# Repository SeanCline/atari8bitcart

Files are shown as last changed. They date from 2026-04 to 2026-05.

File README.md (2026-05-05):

# Cartridge for 8-Bit Atari Computers (400/800/XL/XE)



Configurable Atari 8-bit cartridge PCB for the Atari 400/800/XL/XE line of home computers.

1. **Single 8 KB mode** using one 2764-compatible PROM in the right-hand socket.
2. **Dual 8 KB + 8 KB mode** using two 2764-compatible PROMs.
3. **Single 16 KB mode** using one 27128-compatible PROM in the right-hand socket along with a `74AHCT1G08` for chip-enable logic.

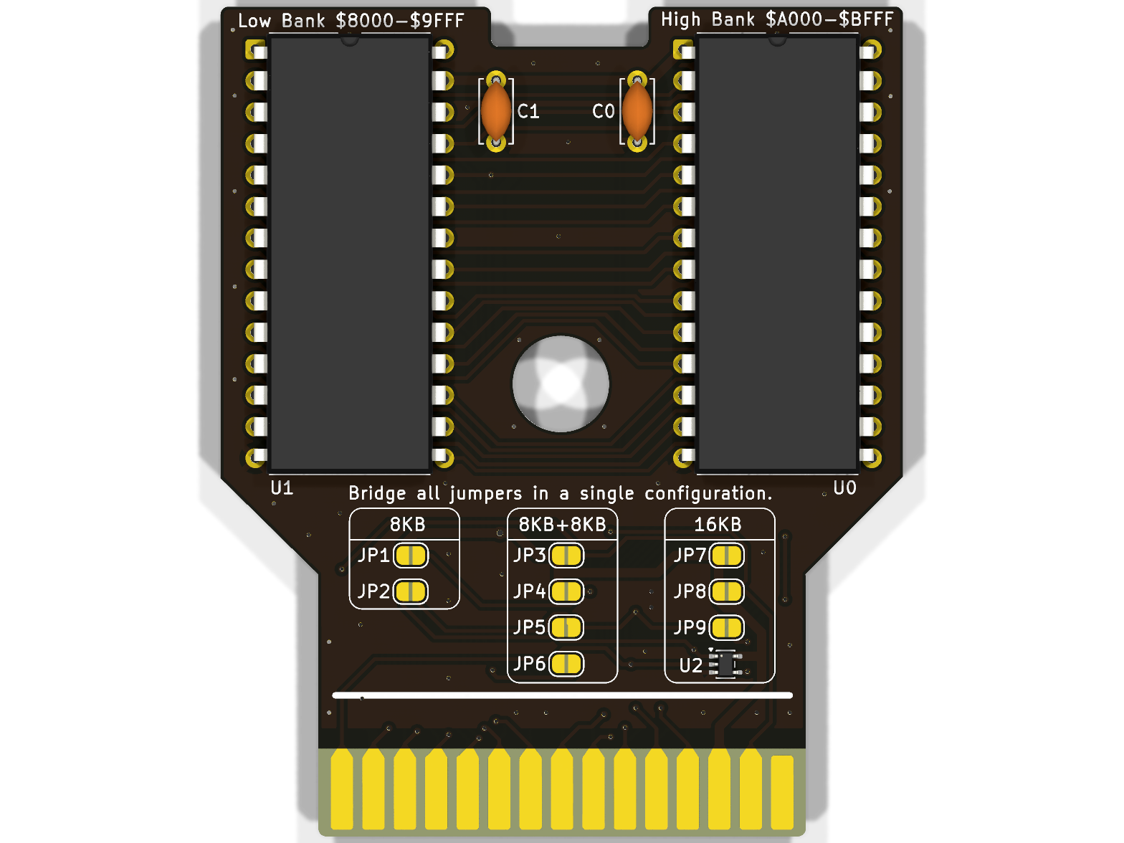
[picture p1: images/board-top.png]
Board top view

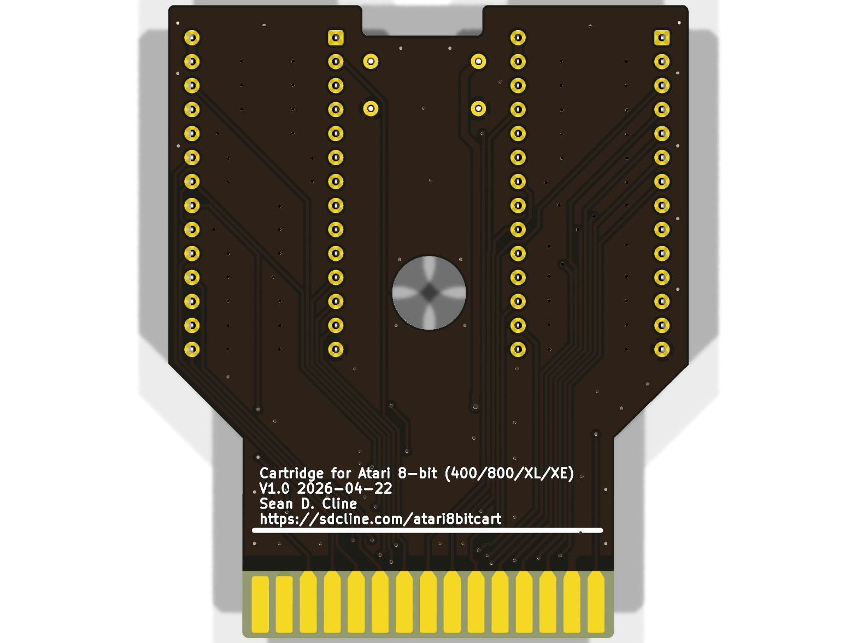
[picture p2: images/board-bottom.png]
Board bottom view


## Hardware Summary

- **U0**: accepts either:
  - a 2764-compatible (8 KB) PROM for both 8KB and 8KB+8KB configurations.
  - a 27128-compatible (16 KB) PROM for 16 KB configurations.
- **U1**: accepts a 2764-compatible (8 KB) PROM in the 8KB+8KB configuration.
- **U2**: `74AHCT1G08` single AND gate used to merge the two chip-enable lines (/S4 and /S5) into a single signal for the 16KB configuration.
- **C0 / C1**: 100 nF bypass capacitors.

## Jumper Configuration

The jumpers are organized into sections, one for each supported configuration.

> ℹ️ **Bridge only the jumpers required for the configuration you intend to use.**

Compoenent and jumper configurations

## Releases

The latest gerber files can be found in the build artifacts section of the [Actions](https://github.com/SeanCline/atari8bitcart/actions) tab.
At the moment, the gerbers are generated for JLCPCB, but it should be pretty easy to send them to a PCB fab of your choosing.

## Schematic

Schematic view

## License

CERN-OHL-W-2.0

See [LICENSE.txt](LICENSE.txt).

---

**Trademark notice:** Atari is a trademark of its respective owner. This project is an independent, unofficial hardware design and is not affiliated with or endorsed by Atari.

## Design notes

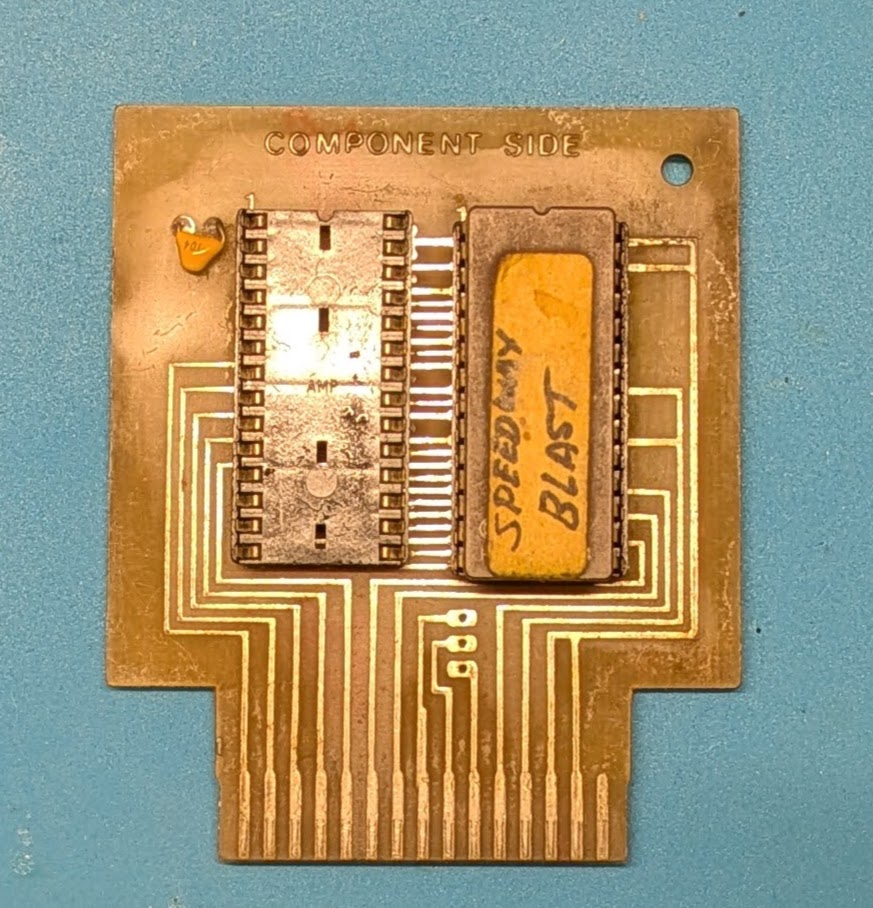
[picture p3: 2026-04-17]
references/Knockoff Cart - Front.jpg

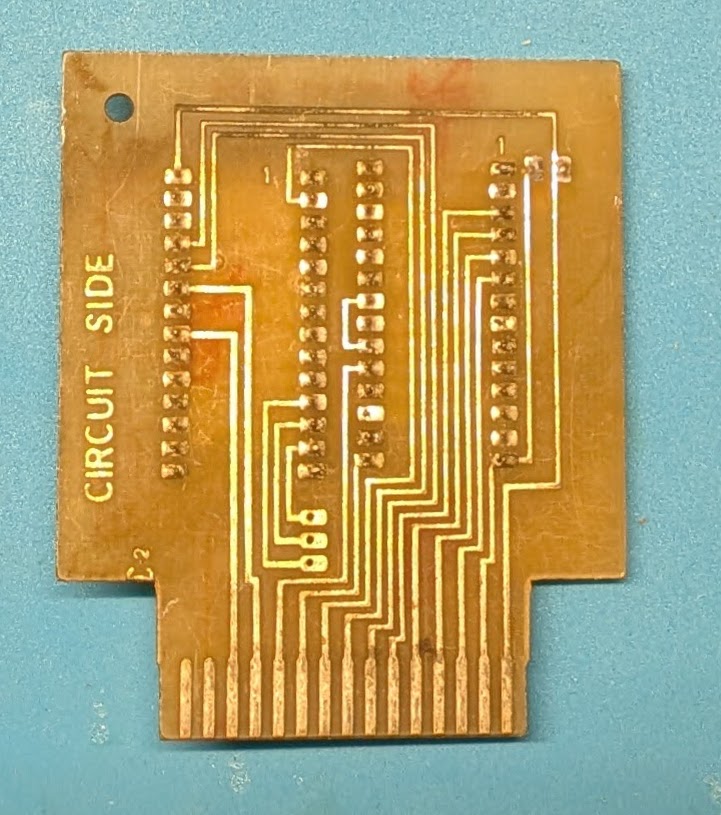
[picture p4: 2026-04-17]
references/Knockoff Cart - Back.jpg

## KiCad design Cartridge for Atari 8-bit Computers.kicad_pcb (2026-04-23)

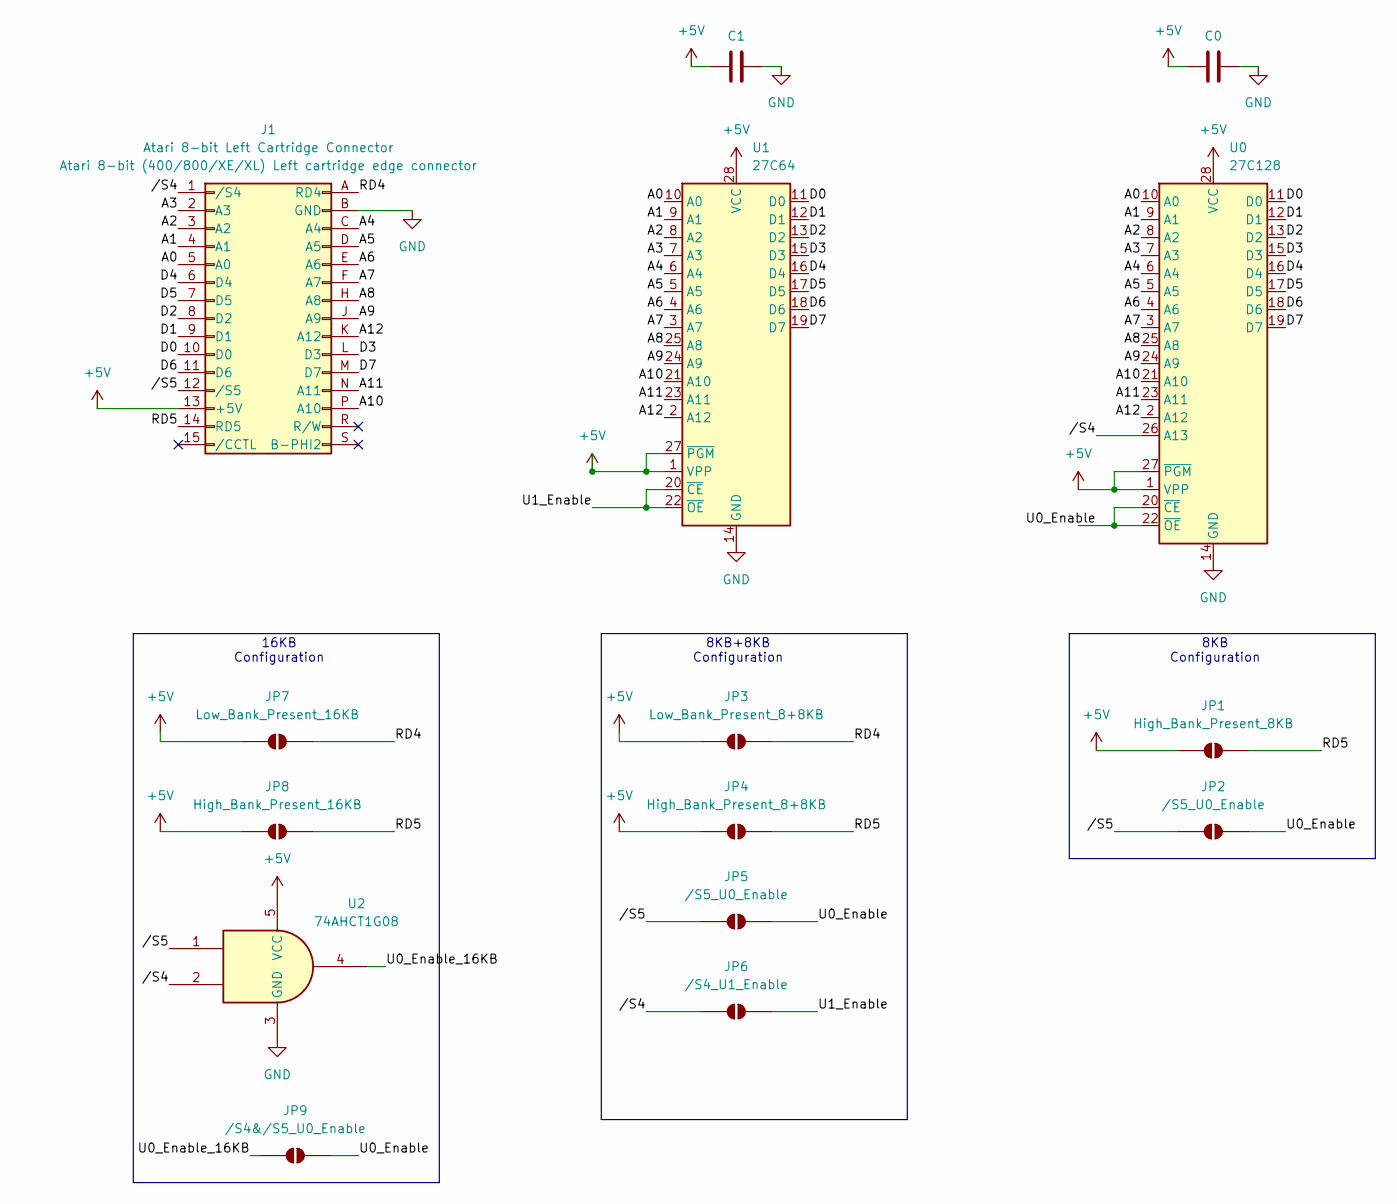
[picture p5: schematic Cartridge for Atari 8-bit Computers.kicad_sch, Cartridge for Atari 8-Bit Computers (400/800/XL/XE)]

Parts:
C0, C1: 100nF; C_Disc_D5.0mm_W2.5mm_P5.00mm; LCSC C2896060
J1: Atari 8-bit Left Cartridge Connector; Atari_8-bit_Cartridge_Connector
JP1: High_Bank_Present_8KB; SolderJumper
JP2, JP5: /S5_U0_Enable; SolderJumper
JP3: Low_Bank_Present_8+8KB; SolderJumper
JP4: High_Bank_Present_8+8KB; SolderJumper
JP6: /S4_U1_Enable; SolderJumper
JP7: Low_Bank_Present_16KB; SolderJumper
JP8: High_Bank_Present_16KB; SolderJumper
JP9: /S4&/S5_U0_Enable; SolderJumper
U0: 27C128; DIP-28_W15.24mm; LCSC C72121
U1: 27C64; DIP-28_W15.24mm; LCSC C72121
U2: 74AHCT1G08; SOT-353_SC-70-5; LCSC C460499

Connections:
+5V: C0.1, C1.1, J1.13 (+5V), JP1.1 (A), JP3.1 (A), JP4.1 (A), JP7.1 (A), JP8.1 (A), U0.1 (VPP), U0.27 (~PGM), U0.28 (VCC), U1.1 (VPP), U1.27 (~PGM), U1.28 (VCC), U2.5 (VCC)
/A0: J1.5 (A0), U0.10 (A0), U1.10 (A0)
/A1: J1.4 (A1), U0.9 (A1), U1.9 (A1)
/A2: J1.3 (A2), U0.8 (A2), U1.8 (A2)
/A3: J1.2 (A3), U0.7 (A3), U1.7 (A3)
/A4: J1.C (A4), U0.6 (A4), U1.6 (A4)
/A5: J1.D (A5), U0.5 (A5), U1.5 (A5)
/A6: J1.E (A6), U0.4 (A6), U1.4 (A6)
/A7: J1.F (A7), U0.3 (A7), U1.3 (A7)
/A8: J1.H (A8), U0.25 (A8), U1.25 (A8)
/A9: J1.J (A9), U0.24 (A9), U1.24 (A9)
/A10: J1.P (A10), U0.21 (A10), U1.21 (A10)
/A11: J1.N (A11), U0.23 (A11), U1.23 (A11)
/A12: J1.K (A12), U0.2 (A12), U1.2 (A12)
/D0: J1.10 (D0), U0.11 (D0), U1.11 (D0)
/D1: J1.9 (D1), U0.12 (D1), U1.12 (D1)
/D2: J1.8 (D2), U0.13 (D2), U1.13 (D2)
/D3: J1.L (D3), U0.15 (D3), U1.15 (D3)
/D4: J1.6 (D4), U0.16 (D4), U1.16 (D4)
/D5: J1.7 (D5), U0.17 (D5), U1.17 (D5)
/D6: J1.11 (D6), U0.18 (D6), U1.18 (D6)
/D7: J1.M (D7), U0.19 (D7), U1.19 (D7)
/RD4: J1.A (RD4), JP3.2 (B), JP7.2 (B)
/RD5: J1.14 (RD5), JP1.2 (B), JP4.2 (B), JP8.2 (B)
/U0_Enable: JP2.2 (B), JP5.2 (B), JP9.1 (A), U0.20 (~CE), U0.22 (~OE)
/U0_Enable_16KB: JP9.2 (B), U2.4
/U1_Enable: JP6.2 (B), U1.20 (~CE), U1.22 (~OE)
//S4: J1.1 (/S4), JP6.1 (A), U0.26 (A13), U2.2
//S5: J1.12 (/S5), JP2.1 (A), JP5.1 (A), U2.1
GND: C0.2, C1.2, J1.B (GND), U0.14 (GND), U1.14 (GND), U2.3 (GND)

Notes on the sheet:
16KB Configuration
8KB Configuration
8KB+8KB Configuration

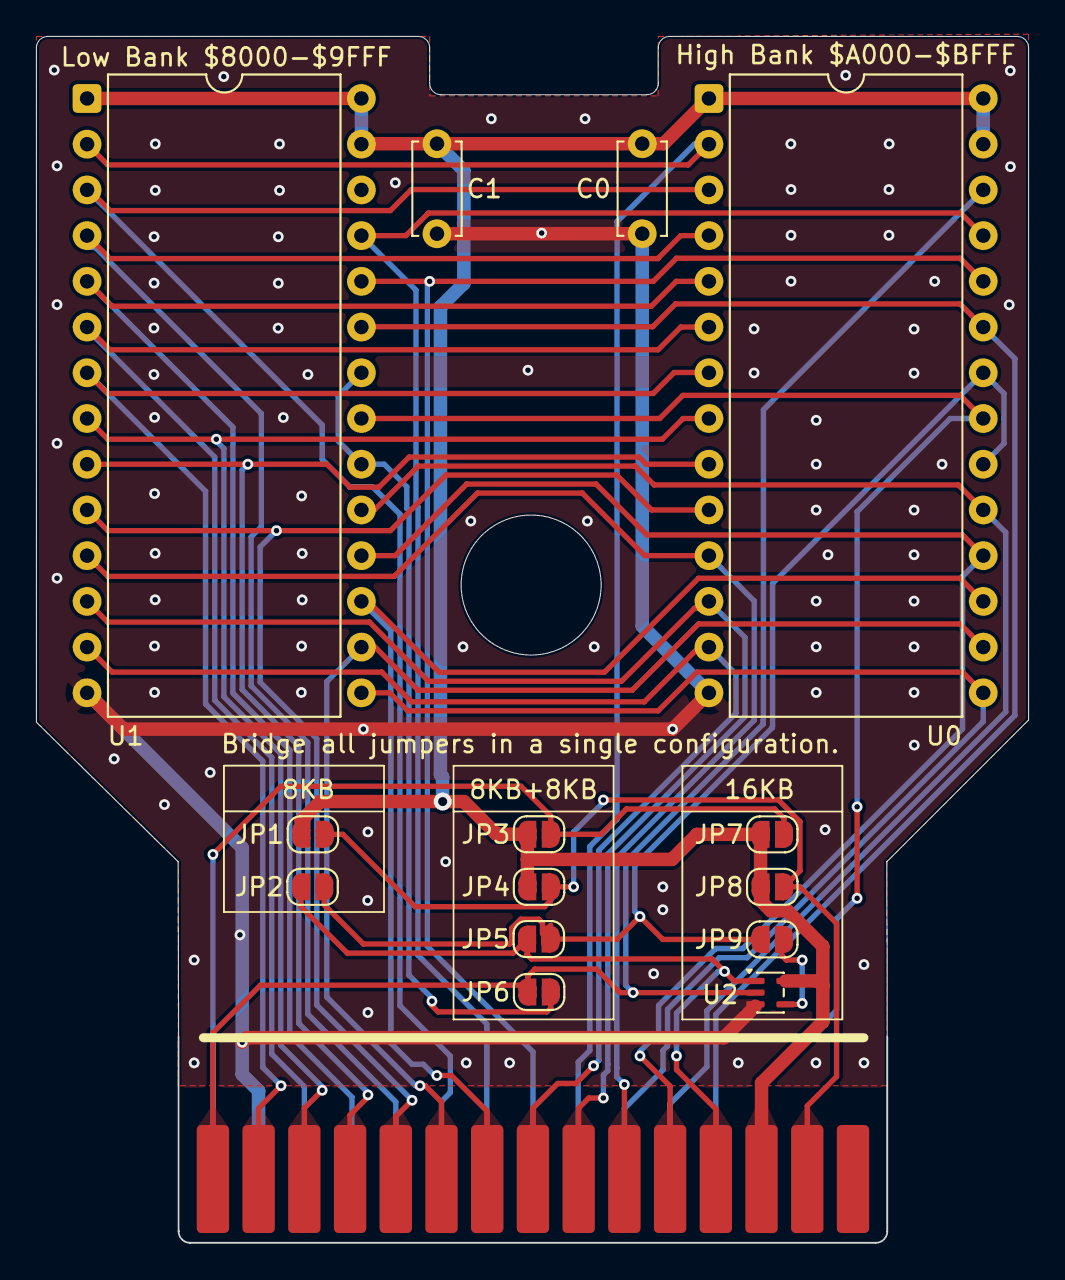
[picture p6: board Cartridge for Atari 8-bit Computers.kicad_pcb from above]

Board: 2 copper layers, 55.1 x 67.0 mm, 15 parts (0 on the bottom side), 30 nets.

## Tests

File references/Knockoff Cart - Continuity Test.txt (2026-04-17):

Nets: (One line per net. Format is Component-Pin.)
	Cart-1 U1-20 U1-22
	Cart-2 U0-7 U1-7
	Cart-3 U0-8 U1-8
	Cart-4 U0-9 U1-9
	Cart-5 U0-10 U1-10
	Cart-6 U0-16 U1-16
	Cart-7 U0-17 U1-17
	Cart-8 U0-13 U1-13
	Cart-9 U0-12 U1-12
	Cart-10 U0-11 U1-11
	Cart-11 U0-18 U1-18
	Cart-12 U0-20 U0-22
	Cart-13 Cart-14 Cart-A U0-1 U0-27 U0-28 U1-1 U1-27 U1-28 C0-1
	Cart-15 NC
	Cart-B U0-14 U1-14 C0-0
	Cart-C U0-6 U1-6
	Cart-D U0-5 U1-5
	Cart-E U0-4 U1-4
	Cart-F U0-3 U1-3
	Cart-H U0-25 U1-25
	Cart-J U0-24 U1-24
	Cart-K U0-2 U1-2
	Cart-L U0-15 U1-15
	Cart-M U0-19 U1-19
	Cart-N U0-23 U1-23
	Cart-P U0-21 U1-21
	Cart-R NC
	Cart-S NC

Components:
	U0: ROM 0, the right ROM on the component side of the PCB.
	U1: ROM 1, the left ROM on the component side of the PCB.
	C0: A 100nF bypass cap.
	Cart: The cart edge connector. 1-15 on the component side. A-S on the circuit side. (G,I,O,Q omitted for legibility)

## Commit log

2026-04-17 Initial Commit. Schematic mostly decoded.
    [Atari 8-bit Cartridge.kicad_pcb, Atari 8-bit Cartridge.kicad_sch]
2026-04-18 Create footprint for cart edge connector.
    [Atari 8-bit Cartridge.kicad_sch]
2026-04-19 Add PCB edge cuts and rough layout.
    [Atari 8-bit Cartridge.kicad_pcb]
2026-04-19 Preliminary board layout.
    [Atari 8-bit Cartridge.kicad_pcb]
2026-04-19 Increase hole and notch size for better fit with case.
    [Atari 8-bit Cartridge.kicad_pcb]
2026-04-21 Lay out configuration jumpers.
    This required moving quite a bit around to make room.
    [Atari 8-bit Cartridge.kicad_pcb, Atari 8-bit Cartridge.kicad_sch]
2026-04-21 Remove soldermask from edge connector.
    It can wear off and gunk up the cartridge slot.
    [Atari 8-bit Cartridge.kicad_pcb]
2026-04-21 First routing pass of back copper.
    [Atari 8-bit Cartridge.kicad_pcb, Atari 8-bit Cartridge.kicad_sch]
2026-04-21 Finish routing front and back copper.
    [Atari 8-bit Cartridge.kicad_pcb]
2026-04-21 Add ground fills and via stitching.
    [Atari 8-bit Cartridge.kicad_pcb]
2026-04-22 Rename the project.
    `Atari` being at the beginning of the name makes it seem like it's an
    official project. Renaming should prevent any confusion.
    [Cartridge for Atari 8-bit Computers.kicad_pcb, Cartridge for Atari 8-bit Computers.kicad_sch]
2026-04-22 Build the JLCPCB gerbers as a Github action.
    Additionally, fix some DRC errors introduced with the stitching vias and
    add a copyright disclaimer to the readme.
    [Cartridge for Atari 8-bit Computers.kicad_pcb]
2026-04-22 Add LCSC component part numbers for assembly.
    [Cartridge for Atari 8-bit Computers.kicad_sch]
2026-04-22 Remove JLCJLCJLCJLC placeholder text for run number.
    It seems JLCPCB no longer needs a production run number anymore.
    Additionally, generate preview images as during the CI build.
    [Cartridge for Atari 8-bit Computers.kicad_pcb]
2026-04-22 Change the CI's docker image to Kicad 10 instead of the nightly builds.
2026-04-22 Change the PCB color to black.
    [Cartridge for Atari 8-bit Computers.kicad_pcb]
2026-04-23 Allow through-hole components when generating the BOM/CPL.
    [Cartridge for Atari 8-bit Computers.kicad_pcb, Cartridge for Atari 8-bit Computers.kicad_sch]
2026-04-23 Exclude solder jumper footprints from the CPL file.
    Fabs can get confused when a component exists in the CPL but not in the
    BOM.
    [Cartridge for Atari 8-bit Computers.kicad_pcb]
